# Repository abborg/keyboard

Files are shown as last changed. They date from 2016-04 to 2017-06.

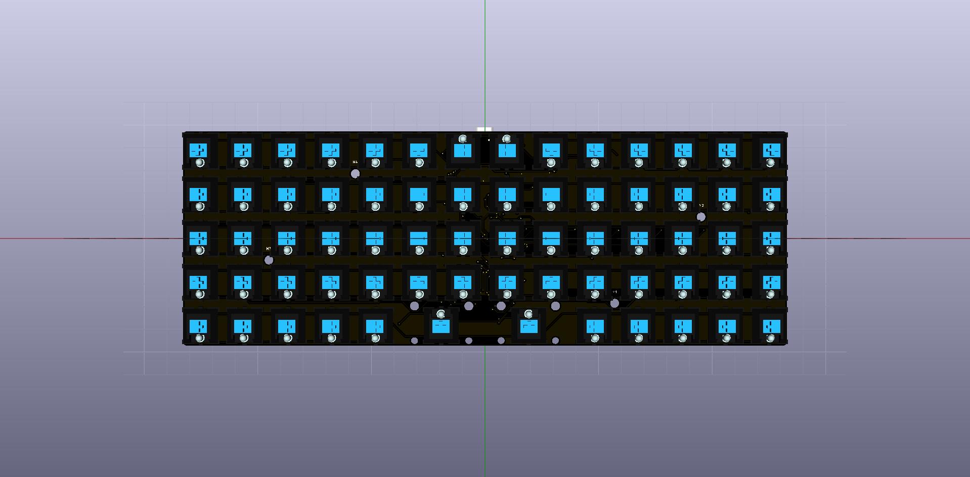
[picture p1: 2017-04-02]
KiCad/keyboard-front.jpg

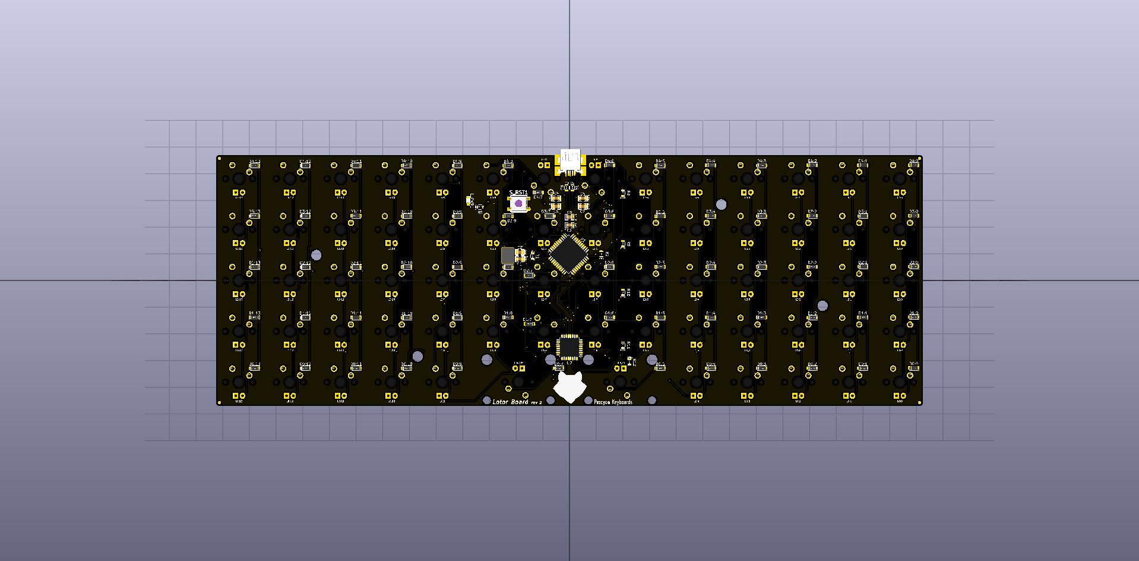
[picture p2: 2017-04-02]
KiCad/keyboard-back.jpg

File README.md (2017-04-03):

Keyboard
========

This repository is dedicated to information and the process of constructing my own custom mechanical keyboard. The hope is that this will be used to store my own notes and layout for future use or modification.

## Layout  

The layout is a unique design I have developed after studying other popular layouts. It has yet to be tested and will require a fair amount of getting used to compared to other layouts. It attempts to utilize the Workman layout and reduce the size of modifier keys. The layout was designed with intuition in mind. As such, much of the layout is symmetrical in an attempt to provide a regular structure to the placement of non-alphabet keys. The idea behind this is that one can make a good guess of where a symbol key is based upon the location of similar keys. Working with a keyboard with access to the microcontroller allows for the layout to be adjusted to suite the needs of the user. 

<sub>[View Layout](http://www.keyboard-layout-editor.com/#/gists/b67145701f86c79b1c43)</sub>  

Inspired by:
------------

Jack Humbert, of [Ortholinear Keyboards](www.ortholinearkeyboards.com)

Will Yager, with his [MicroMechBoard](http://yager.io/keyboard/keyboard.html)

The members of [r/olkb](http://www.reddit.com/r/olkb)

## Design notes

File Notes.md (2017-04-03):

## Metal:
Using 6061 aluminum 100mm x 273mm x 12mm bar for case  
Using 6061 aluminum 100mm x 273mm x 1.5mm sheet for plate  
MetalsDepot offers 0.5 inch x 4 inch 6061 Aluminum flat bar with custom length of 0' 10 3/4" for $15.93 + S/H  
MetalsDepot offers 0.063 inch thick 6061 Aluminum sheet with custom width of 4" and custom length of 0' 10 3/4" for $18.06 + S/H  
MetalsDepot total cost (w/ shipping) $63.39  

### Fabrication:
options to consider  
http://www.thetekmill.com/  
http://www.wagner-machine.com/  
http://www.shape-master.com/  

## Plate:
[Keyboard Layout Editor](http://www.keyboard-layout-editor.com/#/gists/b67145701f86c79b1c43)  
[Keyboard Plate CAD Drawer](http://builder.swillkb.com/)  

## Case:
275mm x 102.5mm x 13mm (l x w x h)
1mm radius outer top edge  
1mm radius inner top edge  
13mm x 1mm insets for rubber feet in corners (d x h)  
4.25mm x 8mm hole in center of back edge  
45° angle on bottom edge  

## Cover:
275mm x 102.5mm x 19mm (l x w x h)  
1mm radius outer bottom edge  
1mm radius inner bottom edge  
45° angle on top edge  

## PCB:
### Devices:
| Device Name | Num Required | Mouser Part # | Manufacturer Part # |
|--- |:---:|:---:|---:|
| ATMega32u4 | 1 | [556-ATMEGA32U4-AUR](http://www.mouser.com/ProductDetail/Microchip-Technology-Atmel/ATMEGA32U4-AUR/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) | ATMEGA32U4-AUR  |
| ATTiny88 | 1 | [556-ATTINY88-AU](http://www.mouser.com/ProductDetail/Microchip-Technology-Atmel/ATTINY88-AU/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) | ATTINY88-AU  |
|Resistor 22 Ohm | 2 | [71-CRCW0805J-22](http://www.mouser.com/ProductDetail/Vishay/CRCW080522R0JNTA/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)| CRCW080522R0JNTABC |
|Resistor 100 Ohm | 5 | [71-CRCW0805-100-E3](http://www.mouser.com/ProductDetail/Vishay/CRCW0805100RFKEA/?qs=sGAEpiMZZMu61qfTUdNhG2DpbjADlD3GxPcNG3UnvYk%3d)| CRCW0805100RFKEA |
|Resistor 10 kOhm | 2 | [71-CRCW080510K0FKEB](http://www.mouser.com/ProductDetail/Vishay/CRCW080510K0FKEB/?qs=sGAEpiMZZMu61qfTUdNhG2DpbjADlD3GcSqJrx4YWs0%3d)| CRCW080510K0FKEB |
|Resistor 140 Ohm | 1 | [71-CRCW0603-140-E3](http://www.mouser.com/ProductDetail/Vishay/CRCW0603140RFKEA/?qs=sGAEpiMZZMujMHSoaAZeGU0lxA%2fvZNWc)| CRCW0603140RFKEA |
|Crystal 16MHz | 1 |[581-CX3225CA16000PPQ](http://www.mouser.com/ProductDetail/AVX-Kyocera/CX3225CA16000P0HPQCC/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) | CX3225CA16000P0HPQCC |
|Capacitor 22pF |2 | [77-VJ0805A220GXXCBC](http://www.mouser.com/ProductDetail/Vishay/VJ0805A220GXXCW1BC/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)| VJ0805A220GXXCW1BC |
| Capacitor 1uF | 2 | [77-VJ0805Y105JXQTBC](http://www.mouser.com/ProductDetail/Vishay/VJ0805Y105JXQTW1BC/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)| VJ0805Y105JXQTW1BC |
| Capacitor 0.1uF | 6 | [77-VJ0805Y104JXXAC](http://www.mouser.com/ProductDetail/Vishay/VJ0805Y104JXXAC/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)| VJ0805Y104JXXAC |
| Cherry Mx Clear | 68 | [540-MX1A-C1NW](http://www.mouser.com/ProductDetail/CHERRY/MX1A-C1NW/?qs=%2fha2pyFaduhq8Eet0S7vJZRQrJ5ARolZRjRGrDPgpGI%3d) | MX1A-C1NW |
| Diode | 68 | [78-1N4148W-E3-18](http://www.mouser.com/ProductDetail/Vishay-Semiconductors/1N4148W-E3-18/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) | 1N4148W-E3-18 |
| Keyswitch LED | 68 |  [828-OVLAW4CB7](http://www.mouser.com/ProductDetail/TT-Electronics/OVLAW4CB7/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) | OVLAW4CB7 |
| Power LED | 1 |  [630-HSMG-C170](http://www.mouser.com/ProductDetail/Broadcom-Limited/HSMG-C170/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) | HSMG-C170 |
| Switch | 1 | [642-DTSMW67T](http://www.mouser.com/ProductDetail/Apem/ADTSMW67TV/?qs=sGAEpiMZZMsgGjVA3toVBOI7nILP73PyWCtsFyAcyoI%3d) | ADTSMW67TV |
| Mini USB-B Connector | 1 | [538-67503-1020](http://www.mouser.com/ProductDetail/Molex/67503-1020/?qs=sGAEpiMZZMtDa8bhoiaN7Dp%2fkqK5DKnm) | 67503-1020 |

PCB will support grid or MIT-esque layouts and standard placement of capslock LED. Also supports FN key light and bottom right corner capslock.

### Fabrication:
[4pcb.com: $33 each boards](www.4pcb.com)

## Miscellaneous
### USB cable:
[/u/90N1NE's Cord Form](https://docs.google.com/forms/d/1O8-y3vcuR8QClX1kB-gxhwCaVJ4b8tqBf4mBuyMltoc)  
[Pexon's Store](http://pexonpcs.co.uk/)  
[/u/jchan94's Cord Form](https://docs.google.com/forms/d/1i3O6ZZ9YgS6CADAT-xIyotbfbr2Xl6MgCU8oeTNEtNQ/viewform)

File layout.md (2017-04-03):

### [Borgman Layout](http://www.keyboard-layout-editor.com/#/gists/b67145701f86c79b1c43)
```
[{a:7},"",{a:4},"Esc","<\n0","_\n1","@\n2","#\n3","$\n4","%\n5","^\n6","`\n7","*\n8",">\n9","~\n\\",{a:7},""],
["",{a:4},"|\n[\n\n\nF1","Q\n\n\n\nF2","D\n\n\n\nF3","R\n\n\n\nF4","W\n\n\n\nF5","B\n\n\n\nF6","J\n\n\n\nF7","F\n\n\n\nF8","U\n\n\n\nF9","P\n\n\n\nF10",{p:"R1"},"Z\n\n\n\nF11","&\n]\n\n\nF12",{a:7},""],
[{a:4},"Tab","{\n'","A","S","H",{n:true},"T","G","Y",{n:true},"N","E","O","I","}\n\"","Enter"],
["Shift","(\n:","=\n-","!\n,","X","M","C","V","K","L","?\n.","+\n/",")\n;","Shift"],
["Ctrl","Alt","Super","Fn","Del",{w:2},"Bksp",{w:2},"Space","&larr;","&darr;","&uarr;","&rarr;","Caps Lock"]
```

### [Qwerty Layout](http://www.keyboard-layout-editor.com/#/gists/a3920c732301a2b1e937)
```
[{a:7},"",{a:4},"Esc","(\n0","!\n1","@\n2","#\n3","$\n4","%\n5","^\n6","&\n7","*\n8",")\n9","|\n\\",{a:7},""],
["",{a:4},"{\n[\n\n\nF1","Q\n\n\n\nF2","W\n\n\n\nF3","E\n\n\n\nF4","R\n\n\n\nF5","T\n\n\n\nF6","Y\n\n\n\nF7","U\n\n\n\nF8","I\n\n\n\nF9","O\n\n\n\nF10","P\n\n\n\nF11","}\n]\n\n\nF12",{a:7},""],
[{a:4},"Tab","~\n`","A","S","D",{n:true},"F","G","H",{n:true},"J","K","L",":\n;","\"\n'","Enter"],
["Shift","_\n-","Z","X","C","V","B","N","M","<\n,",">\n.","?\n/","+\n=","Shift"],
["Ctrl","Alt","Super","Fn","Del",{w:2},"Bksp",{a:7,w:2},"",{a:4},"&larr;","&darr;","&uarr;","&rarr;","Caps Lock"]
```

### [Borgman Grid](http://www.keyboard-layout-editor.com/#/gists/bce03da974b8195c0e16)
```
[{y:0.5,a:7},"",{a:4},"Esc","(\n0","!\n1","@\n2","#\n3","$\n4","%\n5","^\n6","&\n7","*\n8",")\n9","|\n\\",{a:7},""],
["",{a:4},"{\n[\n\n\nF1","Q\n\n\n\nF2","D\n\n\n\nF3","R\n\n\n\nF4","W\n\n\n\nF5","B\n\n\n\nF6","J\n\n\n\nF7","F\n\n\n\nF8","U\n\n\n\nF9","P\n\n\n\nF10",":\n;\n\n\nF11","}\n]\n\n\nF12",{a:7},""],
[{a:4},"Tab","~\n`","A","S","H",{n:true},"T","G","Y",{n:true},"N","E","O","I","\"\n'","Enter"],
["Shift","_\n-","Z","X","M","C","V","K","L","<\n,",">\n.","?\n/","+\n=","Shift"],
["Ctrl","Alt","Super","Fn","Del","Bksp",{a:7},"","",{a:4},"Space","&larr;","&darr;","&uarr;","&rarr;","Caps Lock"]
```

### [Qwerty Grid](http://www.keyboard-layout-editor.com/#/gists/328b5f2f2a083147eaa4ffbb5ecdb029)
```
[{a:7},"",{a:4},"Esc","(\n0","!\n1","@\n2","#\n3","$\n4","%\n5","^\n6","&\n7","*\n8",")\n9","|\n\\",{a:7},""],
["",{a:4},"{\n[\n\n\nF1","Q\n\n\n\nF2","W\n\n\n\nF3","E\n\n\n\nF4","R\n\n\n\nF5","T\n\n\n\nF6","Y\n\n\n\nF7","U\n\n\n\nF8","I\n\n\n\nF9","O\n\n\n\nF10","P\n\n\n\nF11","}\n]\n\n\nF12",{a:7},""],
[{a:4},"Tab","~\n`","A","S","D",{n:true},"F","G","H",{n:true},"J","K","L",":\n;","\"\n'","Enter"],
["Shift","_\n-","Z","X","C","V","B","N","M","<\n,",">\n.","?\n/","+\n=","Shift"],
["Ctrl","Alt","Super","Fn","Del","Bksp",{a:7},"","",{a:4},"Space","&larr;","&darr;","&uarr;","&rarr;","Caps Lock"]
```

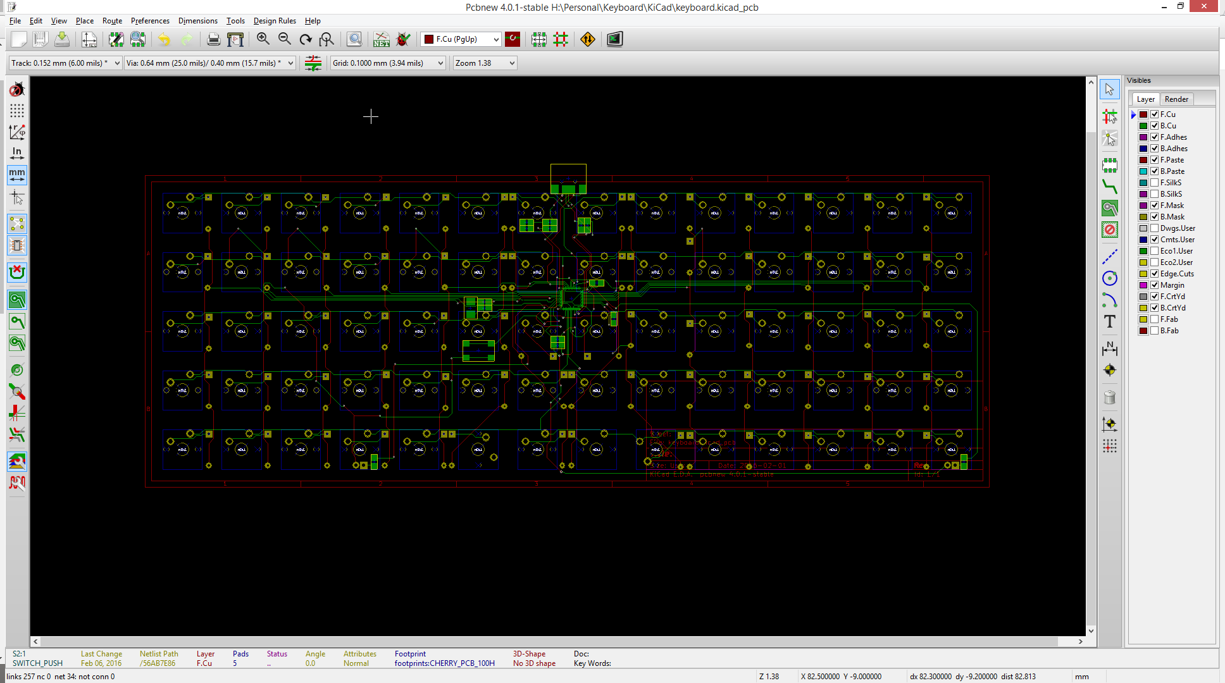
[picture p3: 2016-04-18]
Images/pcb-design-4-17-16.PNG

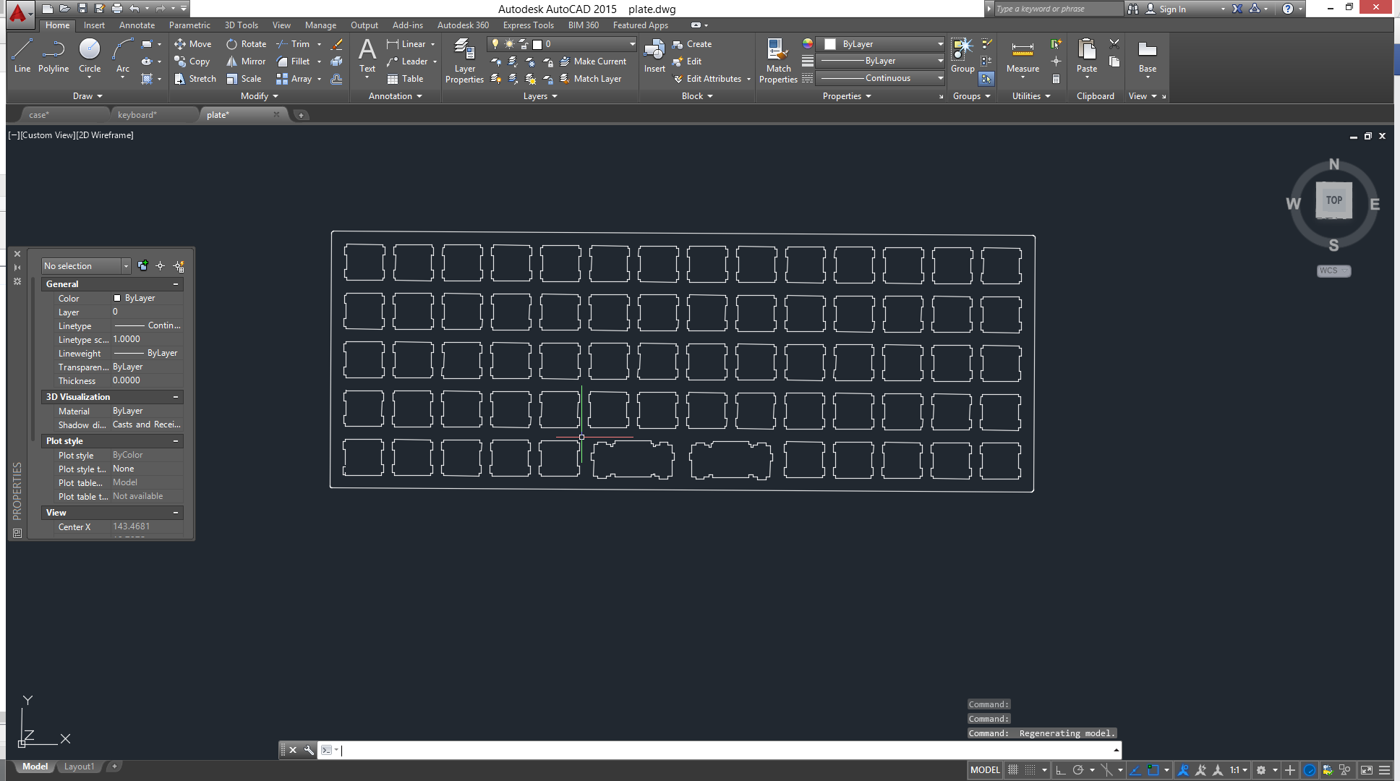
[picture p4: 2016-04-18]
Images/top-plate-4-14-16.PNG

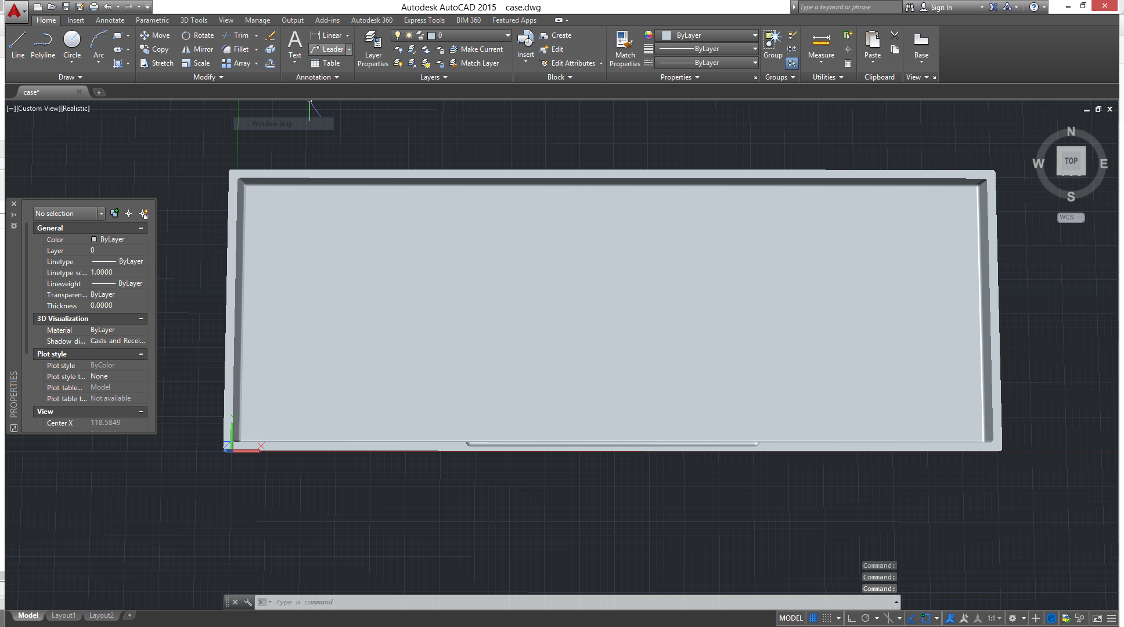
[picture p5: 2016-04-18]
Images/case-bottom-4-14-16.PNG

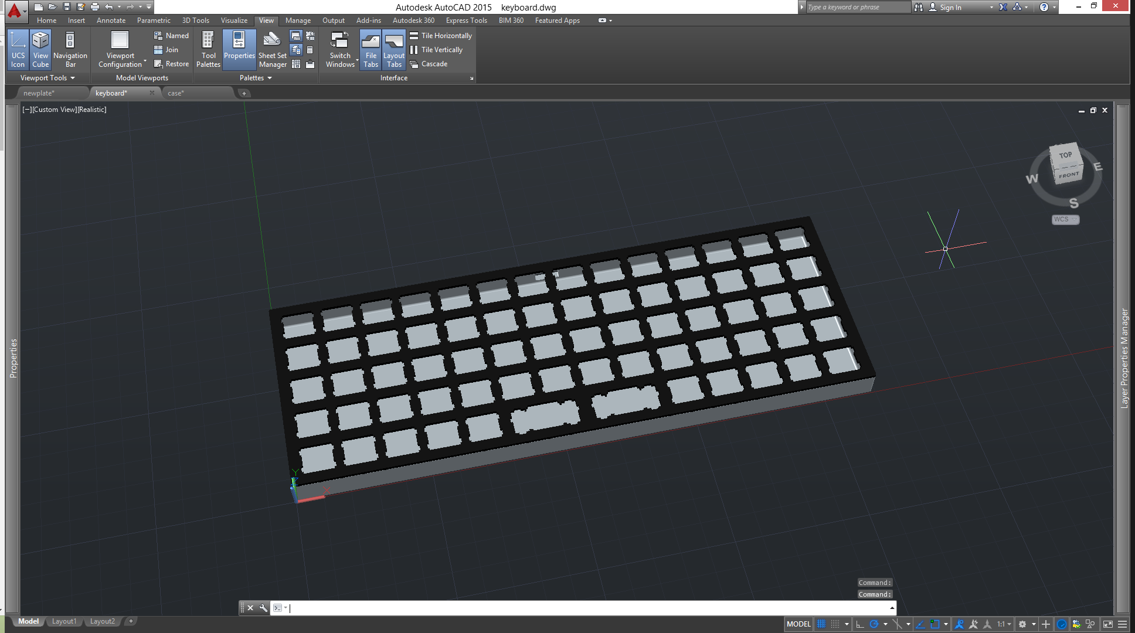
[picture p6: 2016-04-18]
Images/keyboard-4-16-16.PNG

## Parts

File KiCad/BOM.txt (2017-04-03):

MCU Section (0805 components)
Ref       Value         Quantity    Footprint       Part                            Description    
----------------------------------------------------------------------------------------------------------------------
C1,C2     22pF          2           0805            VJ0805A220GXXCW1BC      
C3,C4     1uF           2           0805            VJ0805Y105JXQTW1BC      
C5..C10   0.1uF         6           0805            VJ0805Y104JXXAC 
R1,R2     10 kOhm       2           0805            CRCW080510K0FKEB
R3,R4     22 Ohm        2           0805            CRCW080522R0JNTABC
R5        140 Ohm       1           0805            CRCW0603140RFKEA
R6..R10   100 Ohm       5           0805            CRCW0805100RFKEA

MCU Section (Common)
Ref       Value         Quantity    Footprint       Part                            Description    
----------------------------------------------------------------------------------------------------------------------
X1        16MHz         1           3.2 x 3.2       CX3225CA16000P0HPQCC                 16MHz, 18pf load capacitance, 3.2mm x 2.5mm, 10ppm tolerance & stability
S_RST1    Switch        1           6.3 x 6.2       ADTSMW67TV                      Tactile Switch 6.30 x 6.20 mm
J1        USB MINI-B    1                           67503-1020                      Molex USB Mini-B Recept On-The-Go Rt.Angle                             
U1        ATMEGA32U4    1           TQFP44          ATMEGA32U4-AU                   
U2        ATTINY88      1           TQFP32          ATTINY88-AU

Keyboard Section
Ref       Value         Quantity    Footprint       Part                            Description    
----------------------------------------------------------------------------------------------------------------------
Switches  MX1A          68          CHERRY MX       
D0:0-4:13 1N4148        68          SOD-123         1N4148W-E3-08                   1N4148
L0:0-4:13 LED           68          3mm             OVLAW4CB7                       White 3.2V 20mA LED
L_PWR1                  1           0805            HSMG-C170                       Green 2.2V 20mA LED

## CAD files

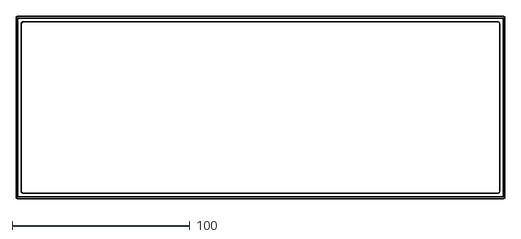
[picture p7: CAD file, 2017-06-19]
AutoCAD/2d/coverbottom.dxf
275.0 x 102.5

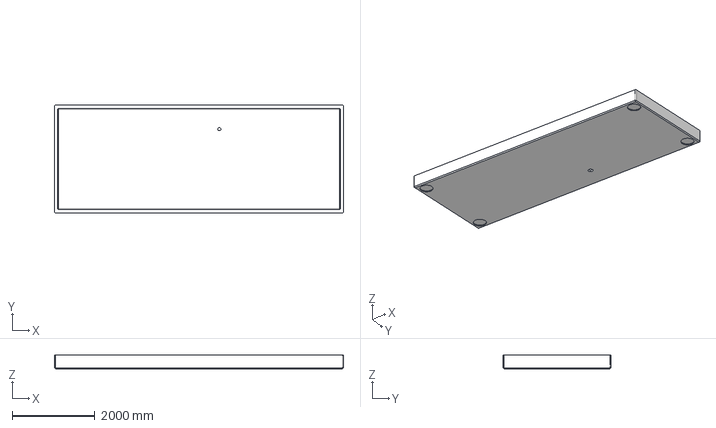
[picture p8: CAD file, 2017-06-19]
AutoCAD/case.igs
6985.0 x 2603.5 x 330.2 mm

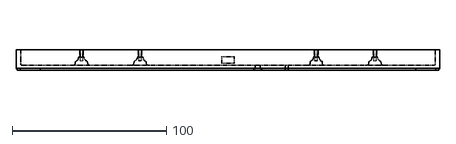
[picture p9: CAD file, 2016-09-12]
AutoCAD/Plots/casefrontview.dxf
275.0 x 13.0

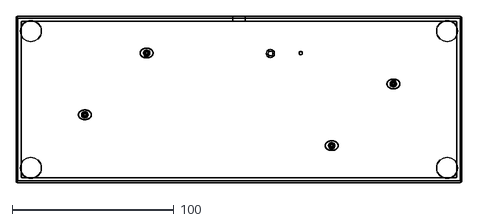
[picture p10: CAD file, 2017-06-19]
AutoCAD/2d/casetop.dxf
275.0 x 102.5

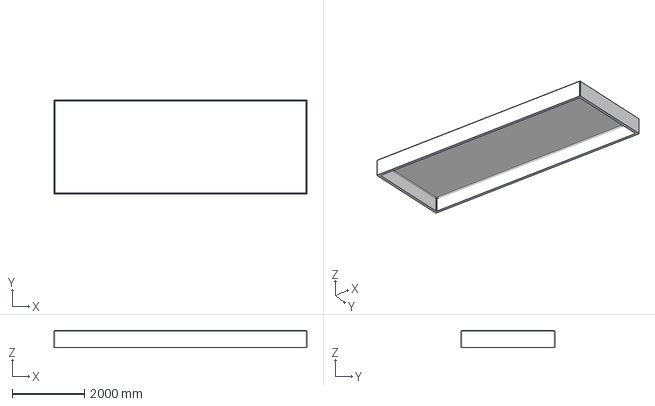
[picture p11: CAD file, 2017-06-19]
AutoCAD/cover.igs
6985.0 x 2603.5 x 482.6 mm

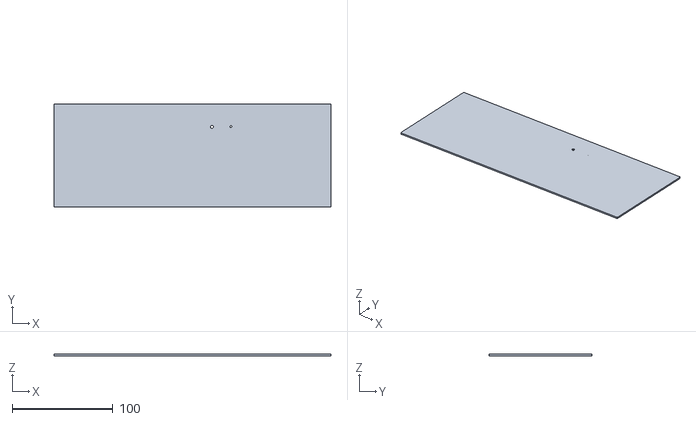
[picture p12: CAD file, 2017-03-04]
AutoCAD/bottom.stl
275.0 x 102.5 x 1.50

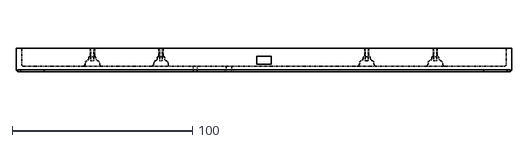
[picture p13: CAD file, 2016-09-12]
AutoCAD/Plots/casebackview.dxf
275.0 x 13.0

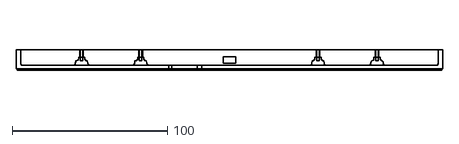
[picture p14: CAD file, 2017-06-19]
AutoCAD/2d/caseback.dxf
275.0 x 13.0

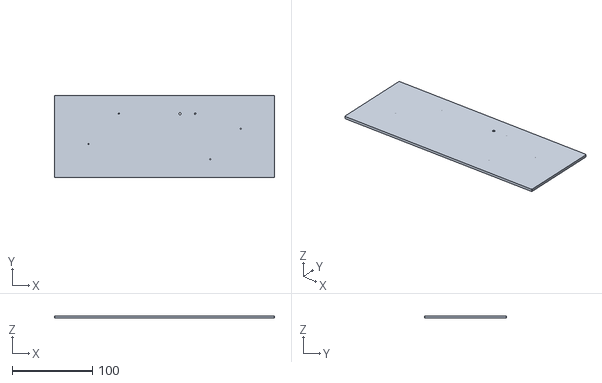
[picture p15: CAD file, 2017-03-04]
AutoCAD/bottom-middle.stl
275.0 x 102.5 x 3.00

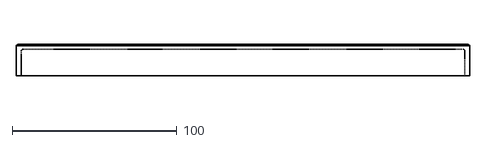
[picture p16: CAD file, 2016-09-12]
AutoCAD/Plots/coverbackview.dxf
275.0 x 19.0

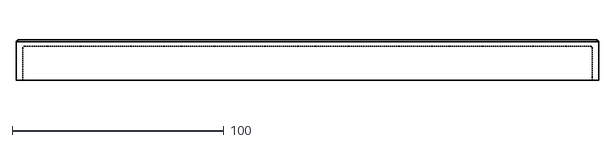
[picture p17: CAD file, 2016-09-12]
AutoCAD/Plots/coverfrontview.dxf
275.0 x 19.0

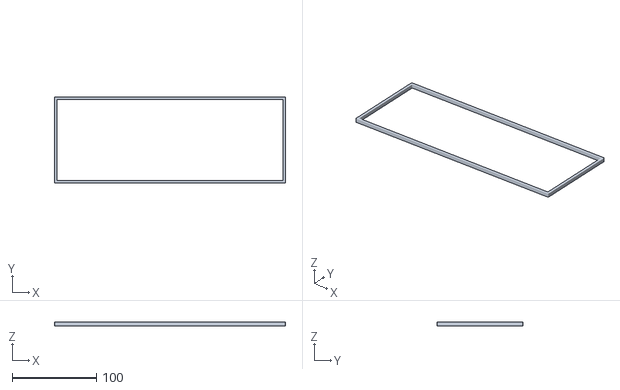
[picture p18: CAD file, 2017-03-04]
AutoCAD/top.stl
275.0 x 102.5 x 4.50

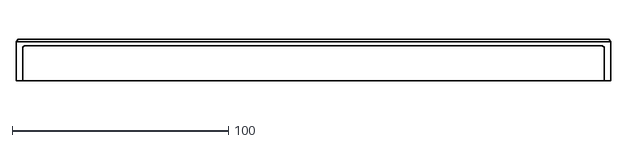
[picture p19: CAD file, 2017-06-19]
AutoCAD/2d/coverback.dxf
275.0 x 19.0

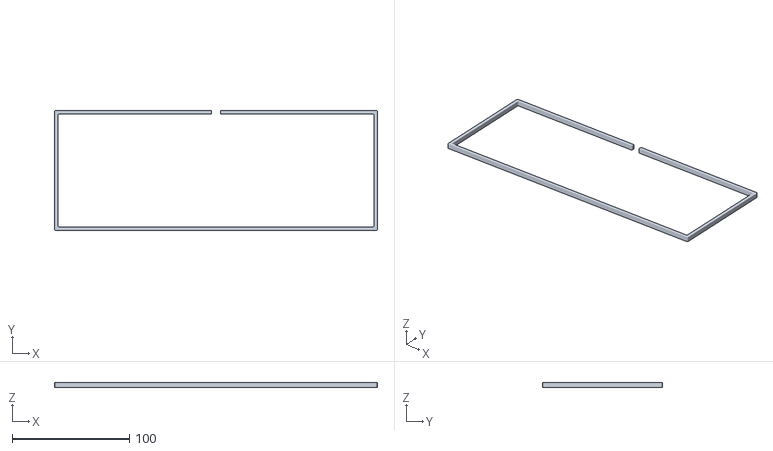
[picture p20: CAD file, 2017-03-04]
AutoCAD/top-middle.stl
275.0 x 102.5 x 4.50

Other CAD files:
AutoCAD/Plots/caseleftview.dxf
AutoCAD/2d/caseright.dxf
AutoCAD/2d/coverright.dxf
AutoCAD/Plots/caserightview.dxf
AutoCAD/Plots/casebottomview.dxf
AutoCAD/Plots/casetopview.dxf
AutoCAD/Plots/coverbottomview.dxf
AutoCAD/Plots/coverleftview.dxf
AutoCAD/Plots/coverrightview.dxf
AutoCAD/Plots/covertopview.dxf
AutoCAD/bottom-middle.dwg
AutoCAD/bottom.dwg
AutoCAD/case.dwg
AutoCAD/case.stl
AutoCAD/cover.dwg
AutoCAD/cover.dxf
AutoCAD/cover.stl
AutoCAD/keyboard.dwg
AutoCAD/plate-MIT.dxf
AutoCAD/plate-grid.dxf
AutoCAD/slices.dwg
AutoCAD/slices.dxf
AutoCAD/slices.stl
AutoCAD/thick-plate-grid.dwg
AutoCAD/thick-plate-grid.stl
AutoCAD/thick_plate-MIT.dwg
AutoCAD/thick_plate-MIT.stl
AutoCAD/top-middle.dwg
AutoCAD/top.dwg

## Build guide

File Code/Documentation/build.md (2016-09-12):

Build Firmware and Program Controller
=====================================

Download and Install
--------------------
### 1. Install Tools

1. **Toolchain** On Windows install [Atmel AVR Toolchain][atmelgcc] for AVR GCC compiler and [Cygwin][cygwin](or [MinGW][mingw]) for shell terminal. On Mac you can use [CrossPack][crosspack] or your favorite package manager. On Linux you can install AVR GCC with your favorite package manager.

2. **Programmer** Install [dfu-programmer][dfu-prog]. GUI tool [Atmel FLIP][flip] also can be used on Windows.

3. **Driver** On Windows when you start DFU bootloader on the chip first time you will see **Found New Hardware Wizard** to install driver. If you install device driver properly you will find chip name like **ATmega32U4** under **LibUSB-Win32 Devices** tree on **Device Manager**. If not you shall need to update its driver on **Device Manager**. You will find the driver in `FLIP` install directory like: `C:\Program Files (x86)\Atmel\Flip 3.4.5\usb\`. In case of `dfu-programmer` install driver distributed with it.

If you use PJRC Teensy you don't need step 2 and 3 above, just get [Teensy loader][teensy-loader].

### 2. Download source
You can find firmware source at github:

- <https://github.com/tmk/tmk_keyboard>

If you are familiar with [`git`][git] tools you are recommended to use it but you can also download zip archive from:

- <https://github.com/tmk/tmk_keyboard/archive/master.zip>

Build firmware
--------------
### 1. Open terminal
Open terminal window to get access to commands. Use Cygwin(or MingGW) shell terminal in Windows or `Terminal.app` on Mac OSX.

### 2. Change directory
Move to project directory in the firmware source.

    cd tmk_keyboard/{'keyboard' or 'converter'}/<project>

### 3. Make
Build firmware using GNU `make` command. You'll see `<project>_<variant>.hex` file in that directory unless something unexpected occurs in build process.

    make -f Makefile.<variant> clean
    make -f Makefile.<variant>

Program Controller
------------------
Now you have **hex** file to program on current directory. This **hex** is only needed to program your controller, other files are used for development and you may leave and forget them.

### 1. Start bootloader
How to program controller depends on controller chip and its board design. To program AVR USB chips you'll need to start it up in bootloader mode. Most of boards with the chip have a push button to let bootloader come up. Consult with your controller board manual.

### 2. Program with DFU bootloader
Stock AVR USB chips have DFU bootloader by factory default. `FLIP` is a DFU programmer on Windows offered by Atmel. `FLIP` has two version of tool, GUI app and command line program. If you want GUI see tutorial below. Open source alternative `dfu-programmer` also supports AVR chips, it is command line tool and runs on Linux, Mac OSX and even Windows.

To program with command of `FLIP` run this. Note that you need to set PATH variable properly.

    $ make -f Makefile.<variant> flip

With `dfu-programmer` run this.

    $ make -f Makefile.<variant> dfu

Or you can execute the command directly as the following.

    $ dfu-programmer <controller> erase --force
    $ dfu-programmer <controller> flash <your_firmware.hex>
    $ dfu-programmer <controller> reset

`<controller>` part will be `atmega32u4` or `atmega32u2` in most cases. See manual of the command for the detail. On Linux and Mac OSX you will need proper permission to program a controller and you can use `sudo` command for this purpose probably. On Linux you also can configure `udev` rules to set permission.

#### FLIP GUI tutorial
1. On menu bar click **Device** -> **Select**, then choose your chip name. (In most cases **ATmega32U2** or **ATmega32U4**)
2. On menu bar click **Settings** -> **Communication** -> **USB**, then click **Open** button on **USB Port Connection** dialog. At this point you'll have to plug into USB and start bootloader.

3. On menu bar click **File** -> **Load HEX File**, then select your firmware hex file on File Selector dialog.
4. On **Operations Flow** panel click **Run** button to load the firmware binary to the chip. Note that you should keep **Erase**, **Blank Check**, **Program** and **Verify** check boxes selected.
5. Re-plug USB cord or click **Start Application** button to restart your controller.
Done.

See also these instructions if needed.

- <http://code.google.com/p/micropendous/wiki/LoadingFirmwareWithFLIP>
- <http://www.atmel.com/Images/doc7769.pdf>

##### Troubleshoot
* **FLIP: AtLibUsbDfu.dll not found**
Remove current driver and re-install one FLIP provides from DeviceManager of WIndows. See <http://imgur.com/a/bnwzy>

### 3. Program with Other programmer
If you are using PJRC Teensy consult with instruction of [Teensy Loader][teensy-loader]. Or run this target with `make` after you install command line version of it.

    $ make -f Makefile.<variant> teensy

You may want to use other programmer like [`avrdude`][avrdude]. In that case you can still use make target `program` for build with configuring `PROGRAM_CMD` in Makefile. See below.

    $ make -f Makefile.<variant> program

[atmelgcc]:     http://www.atmel.com/tools/ATMELAVRTOOLCHAINFORWINDOWS.aspx
[cygwin]:       https://www.cygwin.com/
[mingw]:        http://www.mingw.org/
[crosspack]:    http://www.obdev.at/products/crosspack/index.html
[flip]:         http://www.atmel.com/tools/FLIP.aspx
[dfu-prog]:     http://dfu-programmer.sourceforge.net/
[teensy-loader]:http://www.pjrc.com/teensy/loader.html
[avrdude]:      http://savannah.nongnu.org/projects/avrdude/
[git]:          https://git-scm.com/

Makefile Options
----------------
### 1. MCU and Frequency.

    MCU = atmega32u4       # Teensy 2.0
    #MCU = at90usb1286      # Teensy++ 2.0
    F_CPU = 16000000

Set your MCU and its clock in Hz.

    # Boot Section Size in *bytes*
    #   Teensy halfKay   512
    #   Teensy++ halfKay 2048
    #   Atmel DFU loader 4096
    #   LUFA bootloader  4096
    OPT_DEFS += -DBOOTLOADER_SIZE=4096

If you are using PJRC Teensy use `512` for `BOOTLOADER_SIZE`, otherwise use `4096` unless you are sure.

### 2. Features
Optional. Note that ***comment out*** with `#` to disable them.

    BOOTMAGIC_ENABLE = yes      # Virtual DIP switch configuration(+1000)
    MOUSEKEY_ENABLE = yes       # Mouse keys(+4700)
    EXTRAKEY_ENABLE = yes       # Audio control and System control(+450)
    CONSOLE_ENABLE = yes        # Console for debug(+400)
    COMMAND_ENABLE = yes        # Commands for debug and configuration
    SLEEP_LED_ENABLE = yes      # Breathing sleep LED during USB suspend
    #NKRO_ENABLE = yes          # USB Nkey Rollover - not yet supported in LUFA
    #BACKLIGHT_ENABLE = yes     # Enable keyboard backlight functionality

### 3. Programmer
Optional. Set proper command for your controller, bootloader and programmer. This command can be used with `make program`.

    # avrdude with AVRISPmkII
    PROGRAM_CMD = avrdude -p $(MCU) -c avrispmkII -P USB -U flash:w:$(TARGET).hex

    # avrdude with USBaspLoader
    PROGRAM_CMD = avrdude -p $(MCU) -c usbasp -U flash:w:$(TARGET).hex

    # avrdude with arduino
    PROGRAM_CMD = avrdude -p $(MCU) -c arduino -P COM1 -b 57600 -U flash:w:$(TARGET).hex

Config.h Options
----------------
### 1. Magic command key combination

    #define IS_COMMAND() (keyboard_report->mods == (MOD_BIT(KB_LSHIFT) | MOD_BIT(KB_RSHIFT)))

### 2. Mechanical Locking Support for CapsLock

    /* Mechanical locking CapsLock support. Use KC_LCAP instead of KC_CAPS in keymap */
    #define CAPSLOCK_LOCKING_ENABLE
    /* Locking CapsLock re-synchronize hack */
    #define CAPSLOCK_LOCKING_RESYNC_ENABLE

### 3. Disable Debug and Print

    /* disable debug print */
    #define NO_DEBUG

    /* disable print */
    #define NO_PRINT

### 4. Disable Action Features

    #define NO_ACTION_LAYER
    #define NO_ACTION_TAPPING
    #define NO_ACTION_ONESHOT
    #define NO_ACTION_MACRO
    #define NO_ACTION_FUNCTION

***TBD***

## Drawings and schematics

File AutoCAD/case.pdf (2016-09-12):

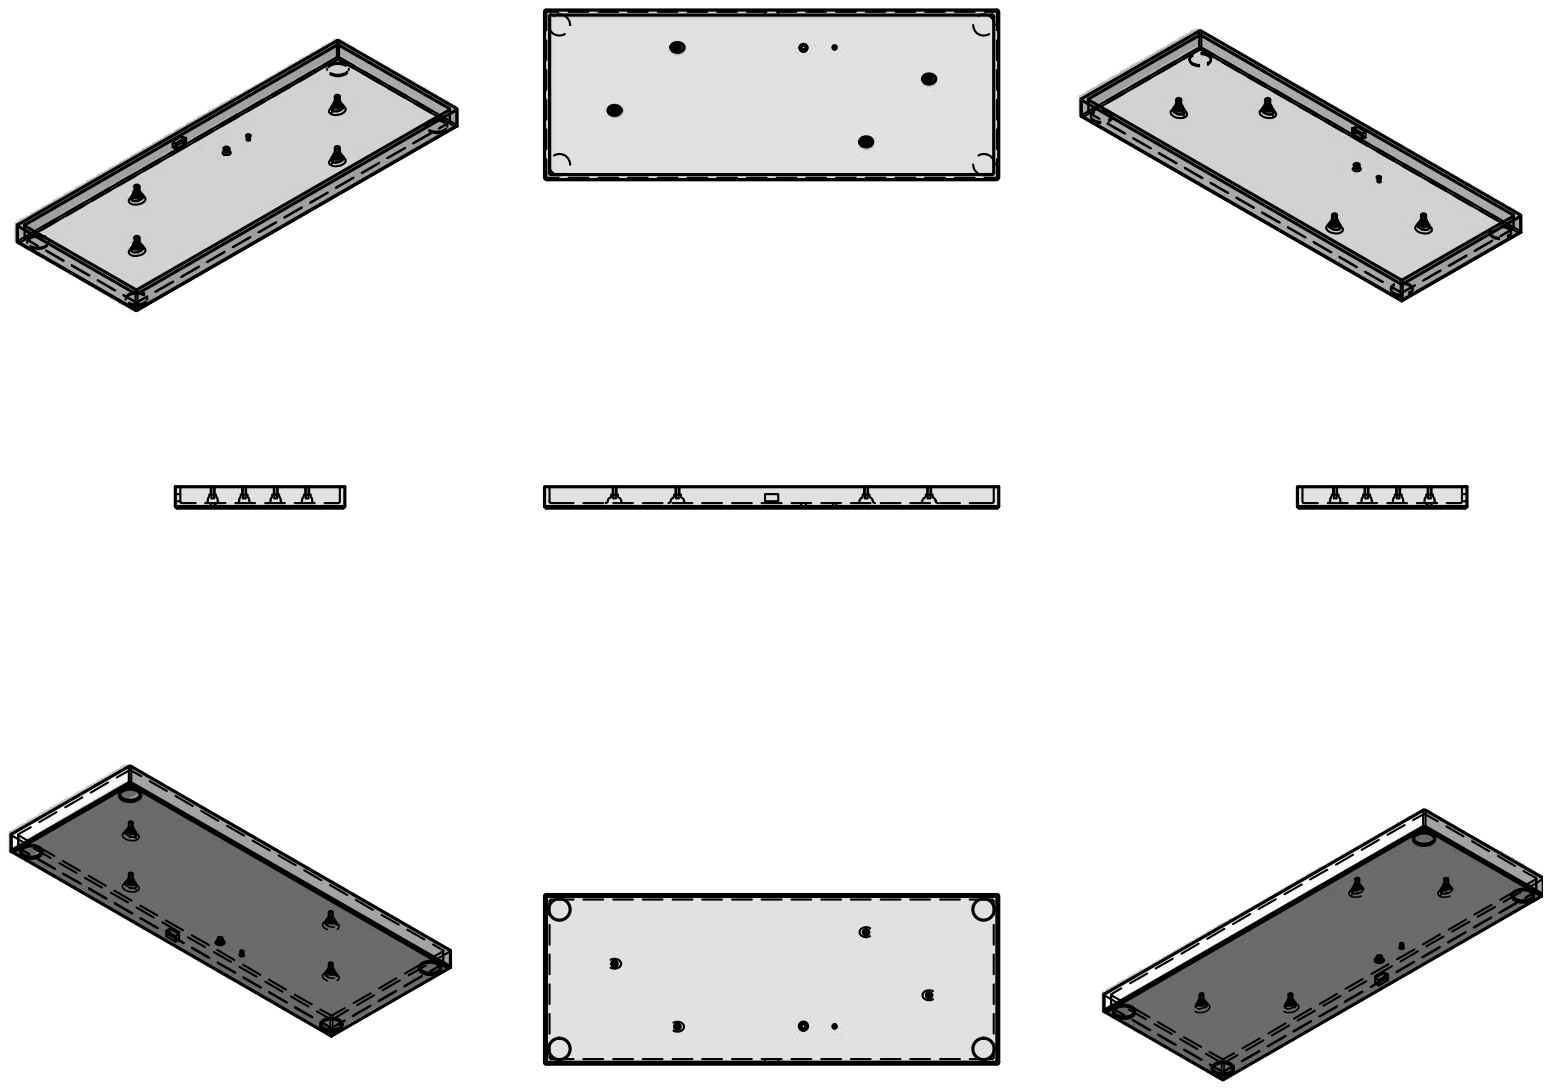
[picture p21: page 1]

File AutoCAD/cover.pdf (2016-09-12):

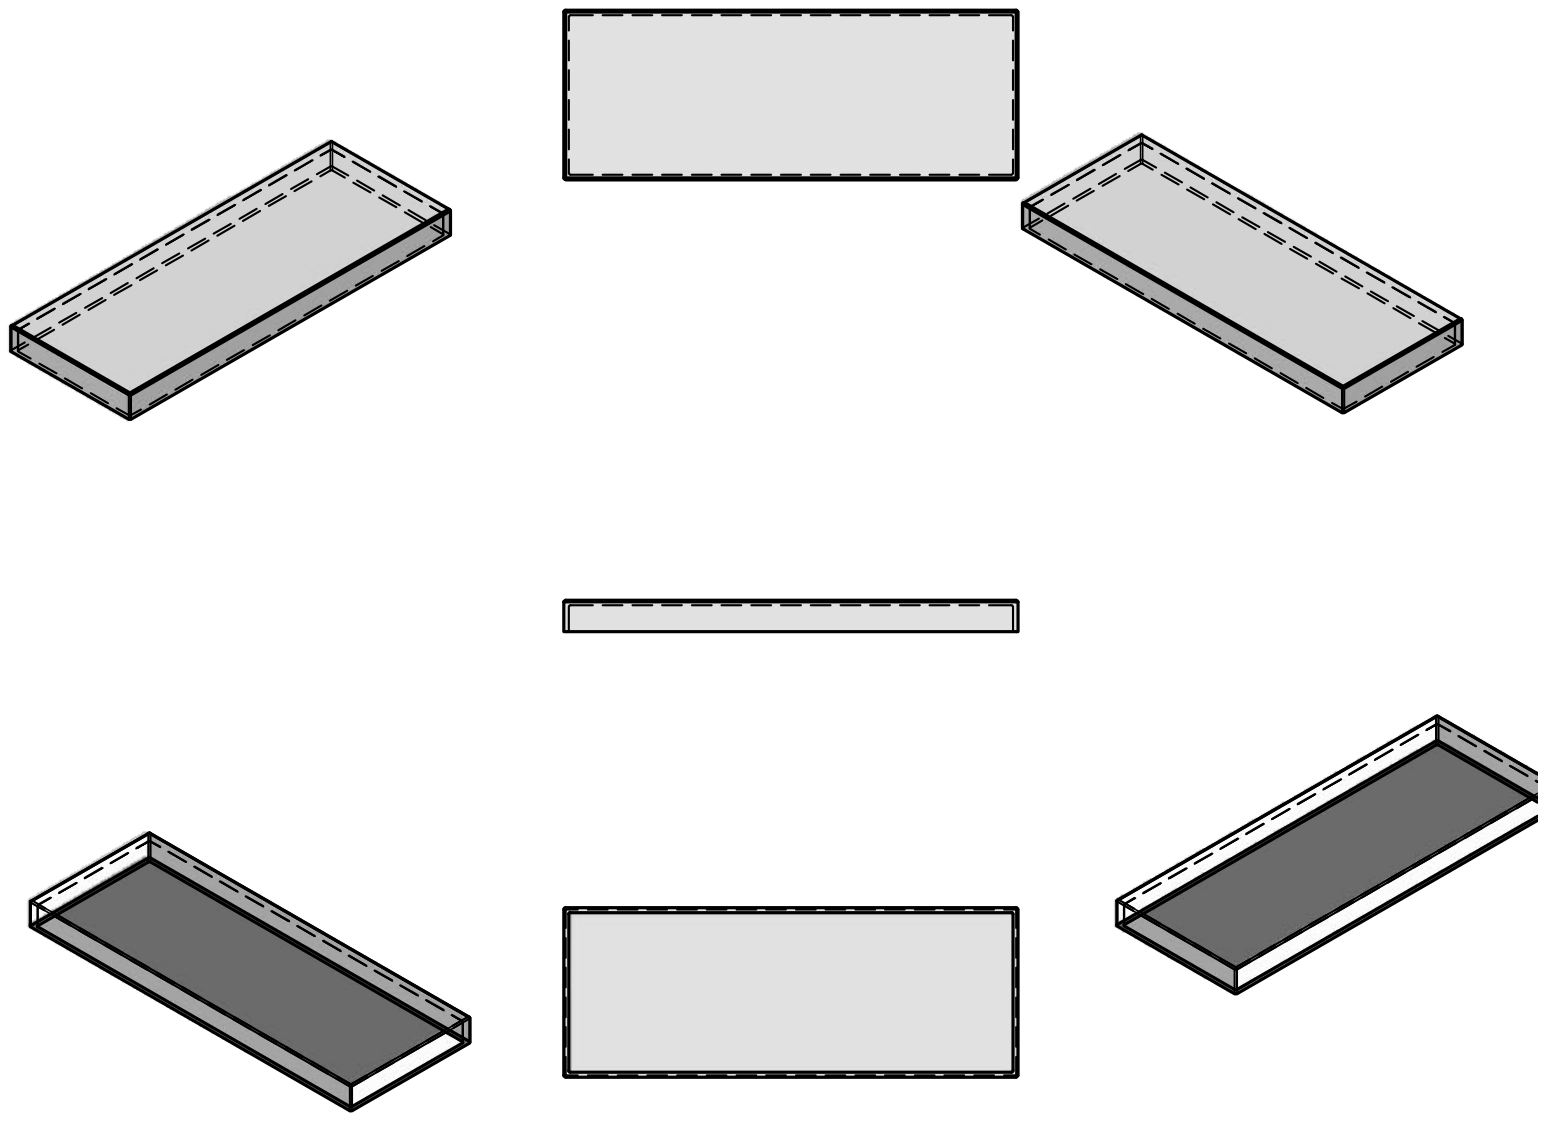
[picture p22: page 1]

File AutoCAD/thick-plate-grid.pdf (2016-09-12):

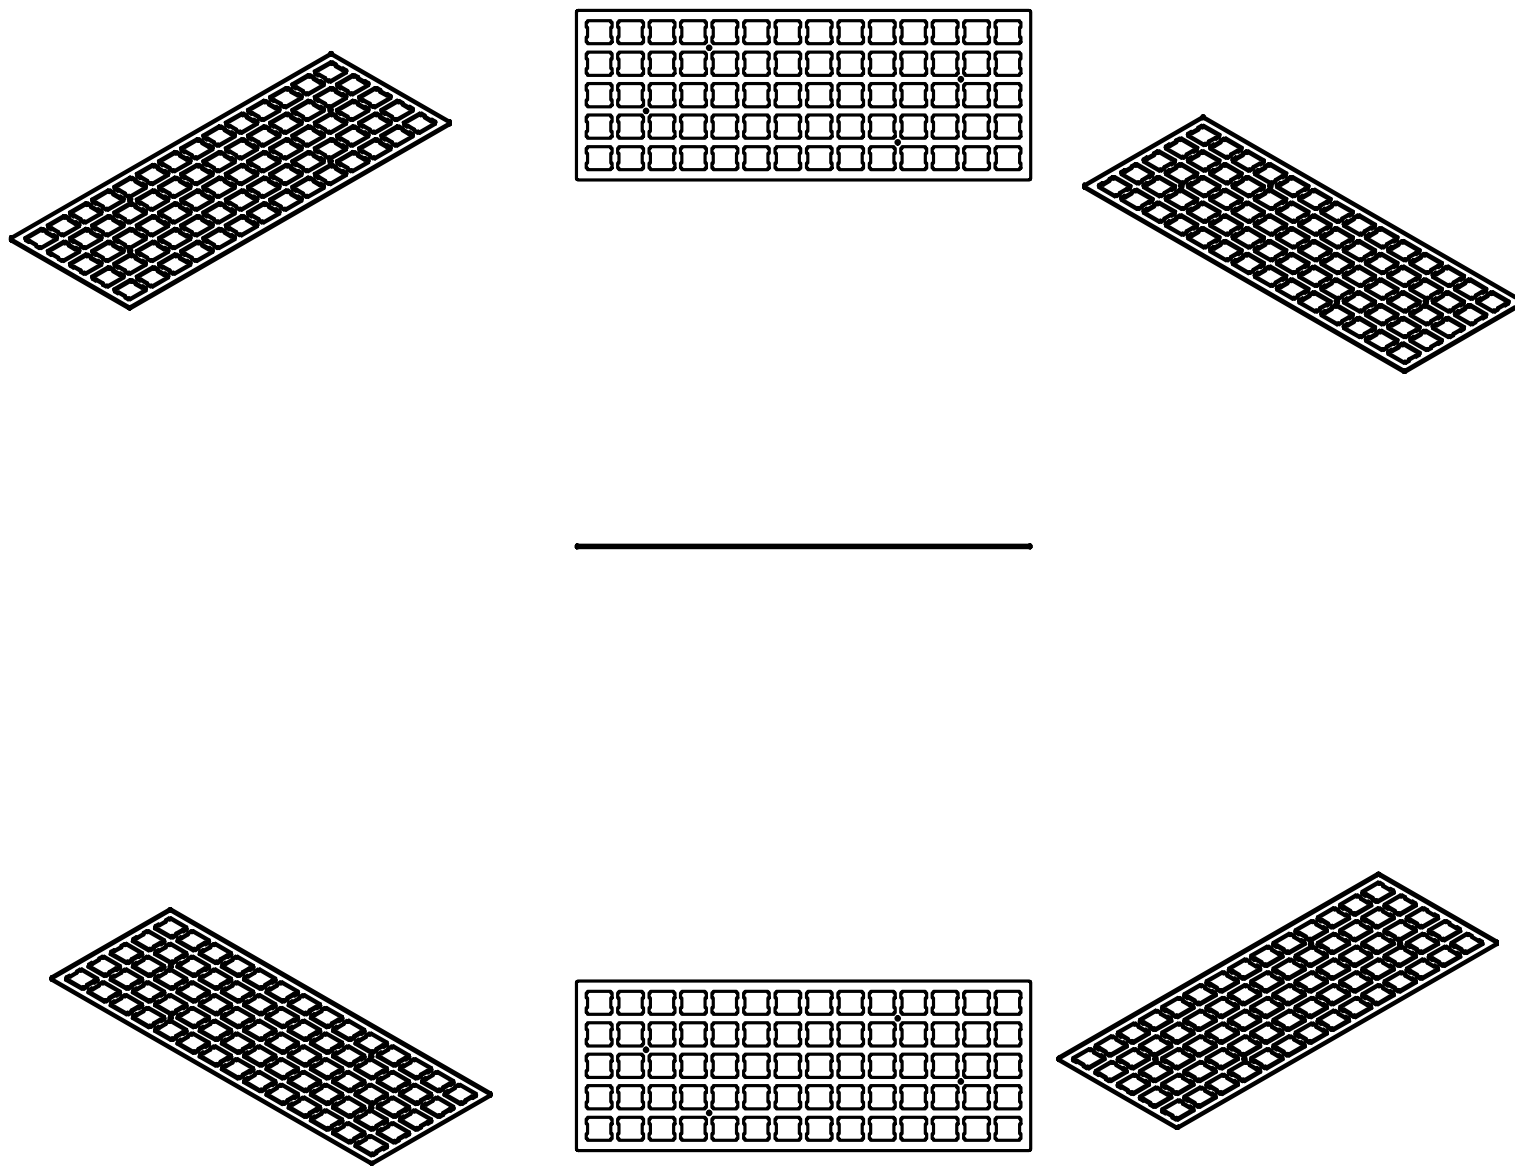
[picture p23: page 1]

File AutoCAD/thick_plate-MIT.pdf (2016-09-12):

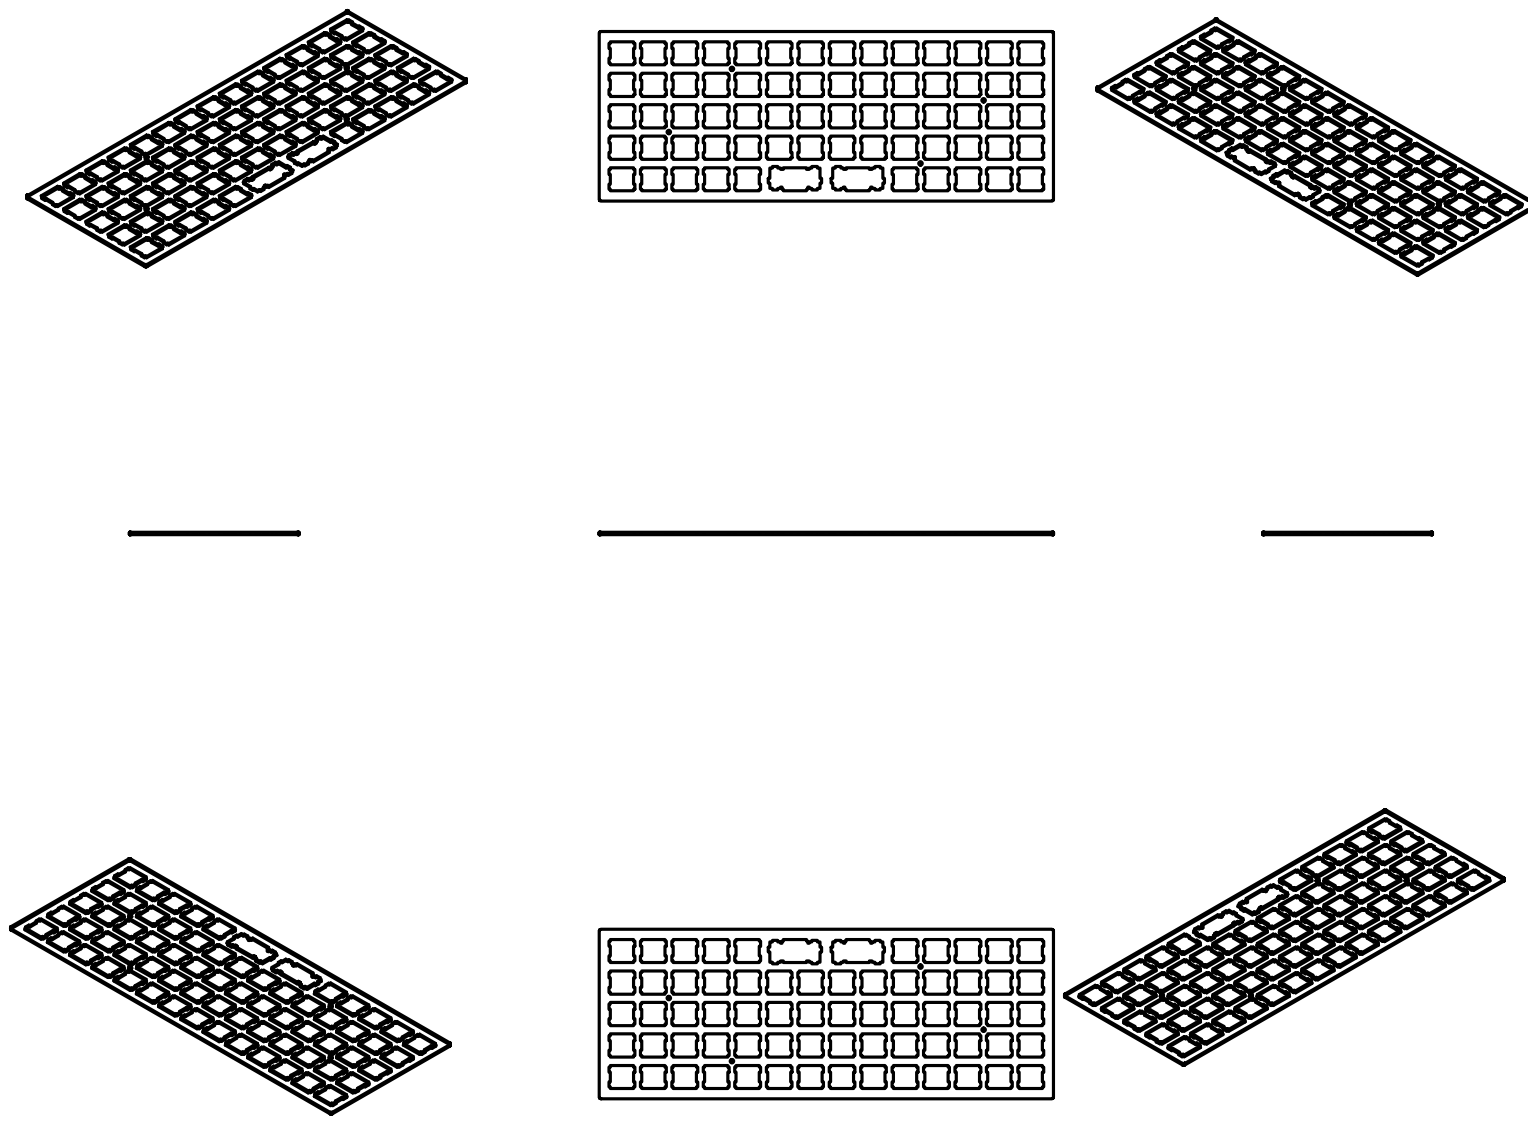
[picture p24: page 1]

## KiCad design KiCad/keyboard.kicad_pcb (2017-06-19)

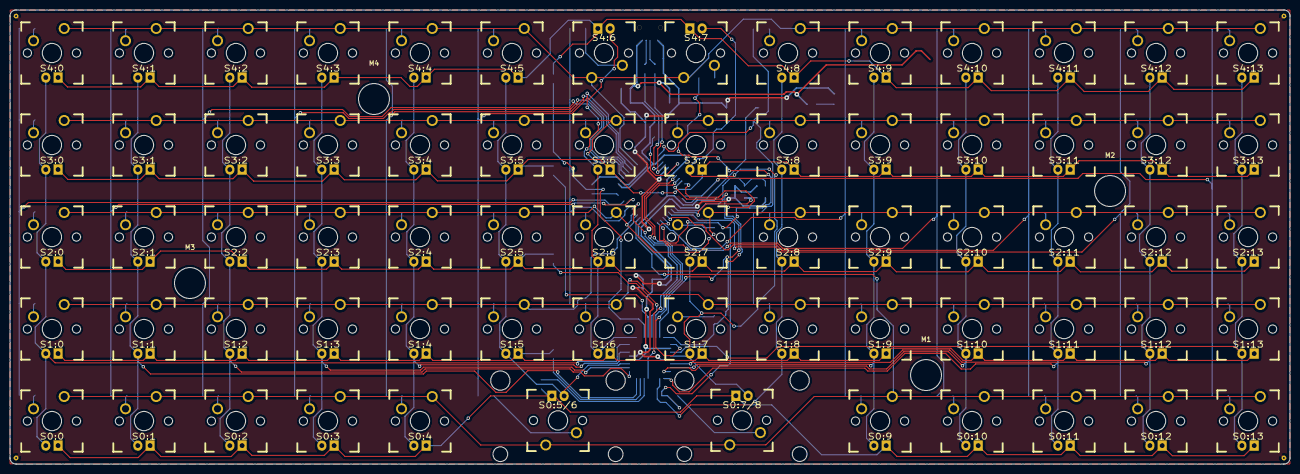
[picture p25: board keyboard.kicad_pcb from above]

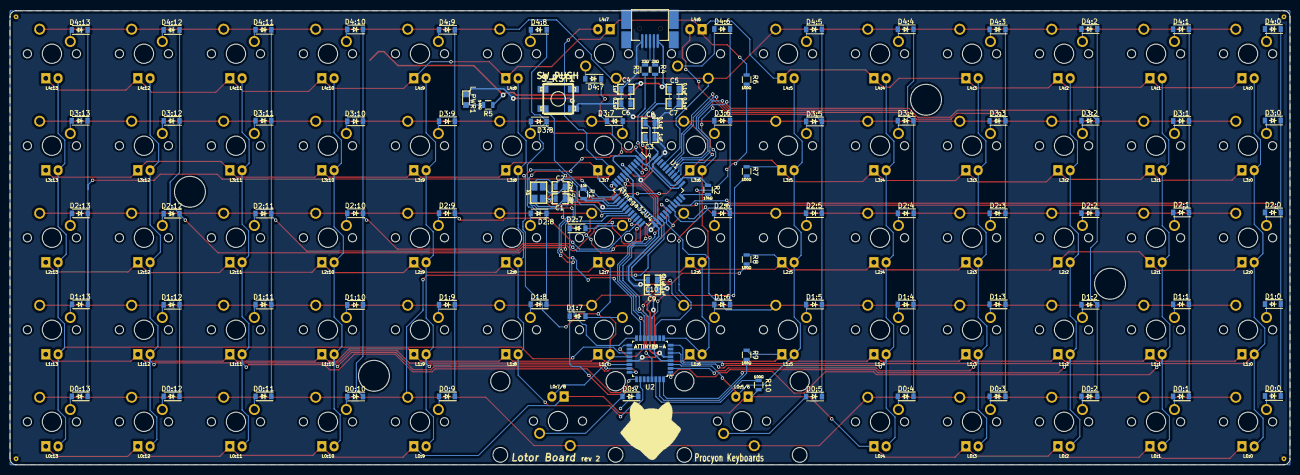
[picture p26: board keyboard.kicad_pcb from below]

Board: 2 copper layers, 265.0 x 94.0 mm, 239 parts (96 on the bottom side), 128 nets.

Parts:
C1, C2: 22pF; 0805C
C3, C4: 1uF; 0805C
C5, C6, C7, C8, C9, C10: 0.1uF; 0805C
D0:0, D0:1, D0:2, D0:3, D0:4, D0:5, D0:7, D0:9, D0:10, D0:11, D0:12, D0:13, D1:0, D1:1, D1:2, D1:3, D1:4, D1:5, D1:6, D1:7, D1:8, D1:9, D1:10, D1:11, D1:12, D1:13, D2:0, D2:1, D2:2, D2:3, D2:4, D2:5, D2:6, D2:7, D2:8, D2:9, D2:10, D2:11, D2:12, D2:13, D3:0, D3:1, D3:2, D3:3, D3:4, D3:5, D3:6, D3:7, D3:8, D3:9, D3:10, D3:11, D3:12, D3:13, D4:0, D4:1, D4:2, D4:3, D4:4, D4:5, D4:6, D4:7, D4:8, D4:9, D4:10, D4:11, D4:12, D4:13: D; SOD-123D
G2: LOGO; racc1
J1: USBMINI_B05; USB_MINI-B-67503
L0:0, L0:1, L0:2, L0:3, L0:4, L0:5/6, L0:7/8, L0:9, L0:10, L0:11, L0:12, L0:13, L1:0, L1:1, L1:2, L1:3, L1:4, L1:5, L1:6, L1:7, L1:8, L1:9, L1:10, L1:11, L1:12, L1:13, L2:0, L2:1, L2:2, L2:3, L2:4, L2:5, L2:6, L2:7, L2:8, L2:9, L2:10, L2:11, L2:12, L2:13, L3:0, L3:1, L3:2, L3:3, L3:4, L3:5, L3:6, L3:7, L3:8, L3:9, L3:10, L3:11, L3:12, L3:13, L4:0, L4:1, L4:2, L4:3, L4:4, L4:5, L4:6, L4:7, L4:8, L4:9, L4:10, L4:11, L4:12, L4:13: LED; CHERRY_MX_LED
L_PWR1: LED; 0805L
M1, M2, M3, M4: MountingHole_6.4mm; MountingHole_6.4mm_M6
R1: 10k; 0805R
R2: 10kΩ; 0805R
R3, R4: 22Ω; 0805R
R5: 140Ω; 0805R
R6, R7, R8, R9, R10: 100Ω; 0805R
S0:0, S0:1, S0:2, S0:3, S0:4, S0:9, S0:10, S0:11, S0:12, S0:13, S1:0, S1:1, S1:2, S1:3, S1:4, S1:5, S1:6, S1:7, S1:8, S1:9, S1:10, S1:11, S1:12, S1:13, S2:0, S2:1, S2:2, S2:3, S2:4, S2:5, S2:6, S2:7, S2:8, S2:9, S2:10, S2:11, S2:12, S2:13, S3:0, S3:1, S3:2, S3:3, S3:4, S3:5, S3:6, S3:7, S3:8, S3:9, S3:10, S3:11, S3:12, S3:13, S4:0, S4:1, S4:2, S4:3, S4:4, S4:5, S4:6, S4:7, S4:8, S4:9, S4:10, S4:11, S4:12, S4:13: SW_PUSH; CHERRY_PCB_100H
S0:5/6, S0:7/8: SW_PUSH; CHERRY_PCB_200H
S_RST1: SW_PUSH; DTSJW-66N
T1, T2, T3, T4: CONN_1; pad
U1: ATmega32U4; ATmega32u4
U2: ATTINY88-A; ATtiny88
X1: CRYSTAL(4pin); Crystal-4pad

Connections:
/led/lcol0: L0:0.2, L1:0.2, L2:0.2, L3:0.2, L4:0.2, U2.8
/led/lcol1: L0:1.2, L1:1.2, L2:1.2, L3:1.2, L4:1.2, U2.32
/led/lcol2: L0:2.2, L1:2.2, L2:2.2, L3:2.2, L4:2.2, U2.1
/led/lcol3: L0:3.2, L1:3.2, L2:3.2, L3:3.2, L4:3.2, U2.2
/led/lcol4: L0:4.2, L1:4.2, L2:4.2, L3:4.2, L4:4.2, U2.6
/led/lcol5: L0:5/6.2, L1:5.2, L2:5.2, L3:5.2, L4:5.2, U2.3
/led/lcol6: L1:6.2, L2:6.2, L3:6.2, L4:6.2, U2.9
/led/lcol7: L0:7/8.2, L1:7.2, L2:7.2, L3:7.2, L4:7.2, U2.20
/led/lcol8: L1:8.2, L2:8.2, L3:8.2, L4:8.2, U2.26
/led/lcol9: L0:9.2, L1:9.2, L2:9.2, L3:9.2, L4:9.2, U2.23
/led/lcol10: L0:10.2, L1:10.2, L2:10.2, L3:10.2, L4:10.2, U2.24
/led/lcol11: L0:11.2, L1:11.2, L2:11.2, L3:11.2, L4:11.2, U2.25
/led/lcol12: L0:12.2, L1:12.2, L2:12.2, L3:12.2, L4:12.2, U2.22
/led/lcol13: L0:13.2, L1:13.2, L2:13.2, L3:13.2, L4:13.2, U2.19
/led/lrow0: R10.2, U2.30
/led/lrow1: R9.2, U2.31
/led/lrow2: R8.2, U2.13
/led/lrow3: R7.2, U2.12
/led/lrow4: R6.2, U2.11
/led/miso: U1.11, U2.16
/led/mosi: U1.10, U2.15
/led/sck: U1.9, U2.17
/led/~reset~: U1.28, U2.29
/led/~ss~: U1.8, U2.14
/matrix/col0: D0:0.1, D1:0.1, D2:0.1, D3:0.1, D4:0.1, U1.31
/matrix/col1: D0:1.1, D1:1.1, D2:1.1, D3:1.1, D4:1.1, U1.30
/matrix/col2: D0:2.1, D1:2.1, D2:2.1, D3:2.1, D4:2.1, U1.37
/matrix/col3: D0:3.1, D1:3.1, D2:3.1, D3:3.1, D4:3.1, U1.38
/matrix/col4: D0:4.1, D1:4.1, D2:4.1, D3:4.1, D4:4.1, U1.39
/matrix/col5: D0:5.1, D1:5.1, D2:5.1, D3:5.1, D4:5.1, U1.40
/matrix/col6: D1:6.1, D2:6.1, D3:6.1, D4:6.1, U1.29
/matrix/col7: D0:7.1, D1:7.1, D2:7.1, D3:7.1, D4:7.1, U1.22
/matrix/col8: D1:8.1, D2:8.1, D3:8.1, D4:8.1, U1.1
/matrix/col9: D0:9.1, D1:9.1, D2:9.1, D3:9.1, D4:9.1, U1.21
/matrix/col10: D0:10.1, D1:10.1, D2:10.1, D3:10.1, D4:10.1, U1.20
/matrix/col11: D0:11.1, D1:11.1, D2:11.1, D3:11.1, D4:11.1, U1.19
/matrix/col12: D0:12.1, D1:12.1, D2:12.1, D3:12.1, D4:12.1, U1.18
/matrix/col13: D0:13.1, D1:13.1, D2:13.1, D3:13.1, D4:13.1, U1.12
/matrix/row0: S0:0.1, S0:1.1, S0:2.1, S0:3.1, S0:4.1, S0:5/6.1, S0:7/8.1, S0:9.1, S0:10.1, S0:11.1, S0:12.1, S0:13.1, U1.25
/matrix/row1: S1:0.1, S1:1.1, S1:2.1, S1:3.1, S1:4.1, S1:5.1, S1:6.1, S1:7.1, S1:8.1, S1:9.1, S1:10.1, S1:11.1, S1:12.1, S1:13.1, U1.26
/matrix/row2: S2:0.1, S2:1.1, S2:2.1, S2:3.1, S2:4.1, S2:5.1, S2:6.1, S2:7.1, S2:8.1, S2:9.1, S2:10.1, S2:11.1, S2:12.1, S2:13.1, U1.27
/matrix/row3: S3:0.1, S3:1.1, S3:2.1, S3:3.1, S3:4.1, S3:5.1, S3:6.1, S3:7.1, S3:8.1, S3:9.1, S3:10.1, S3:11.1, S3:12.1, S3:13.1, U1.36
/matrix/row4: S4:0.1, S4:1.1, S4:2.1, S4:3.1, S4:4.1, S4:5.1, S4:6.1, S4:7.1, S4:8.1, S4:9.1, S4:10.1, S4:11.1, S4:12.1, S4:13.1, U1.41
/~RES~: R1.2, S_RST1.2, U1.13
GND: C1.2, C2.2, C3.2, C4.2, C5.2, C6.2, C7.2, C8.2, C9.2, C10.2, J1.5, L_PWR1.1, R2.1, S_RST1.1, T1.1, T2.1, T3.1, T4.1, U1.5, U1.15, U1.23, U1.35, U1.43, U2.5, U2.21, X1.2, X1.4
unnamed: C1.1, U1.17, X1.1
unnamed: C2.1, U1.16, X1.3
unnamed: C3.1, U1.6
unnamed: D0:0.2, S0:0.2
unnamed: D0:1.2, S0:1.2
unnamed: D0:2.2, S0:2.2
unnamed: D0:3.2, S0:3.2
unnamed: D0:4.2, S0:4.2
unnamed: D0:5.2, S0:5/6.2
unnamed: D0:7.2, S0:7/8.2
unnamed: D0:9.2, S0:9.2
unnamed: D0:10.2, S0:10.2
unnamed: D0:11.2, S0:11.2
unnamed: D0:12.2, S0:12.2
unnamed: D0:13.2, S0:13.2
unnamed: D1:0.2, S1:0.2
unnamed: D1:1.2, S1:1.2
unnamed: D1:2.2, S1:2.2
unnamed: D1:3.2, S1:3.2
unnamed: D1:4.2, S1:4.2
unnamed: D1:5.2, S1:5.2
unnamed: D1:6.2, S1:6.2
unnamed: D1:7.2, S1:7.2
unnamed: D1:8.2, S1:8.2
unnamed: D1:9.2, S1:9.2
unnamed: D1:10.2, S1:10.2
unnamed: D1:11.2, S1:11.2
unnamed: D1:12.2, S1:12.2
unnamed: D1:13.2, S1:13.2
unnamed: D2:0.2, S2:0.2
unnamed: D2:1.2, S2:1.2
unnamed: D2:2.2, S2:2.2
unnamed: D2:3.2, S2:3.2
unnamed: D2:4.2, S2:4.2
unnamed: D2:5.2, S2:5.2
unnamed: D2:6.2, S2:6.2
unnamed: D2:7.2, S2:7.2
unnamed: D2:8.2, S2:8.2
unnamed: D2:9.2, S2:9.2
unnamed: D2:10.2, S2:10.2
unnamed: D2:11.2, S2:11.2
unnamed: D2:12.2, S2:12.2
unnamed: D2:13.2, S2:13.2
unnamed: D3:0.2, S3:0.2
unnamed: D3:1.2, S3:1.2
unnamed: D3:2.2, S3:2.2
unnamed: D3:3.2, S3:3.2
unnamed: D3:4.2, S3:4.2
unnamed: D3:5.2, S3:5.2
unnamed: D3:6.2, S3:6.2
unnamed: D3:7.2, S3:7.2
unnamed: D3:8.2, S3:8.2
unnamed: D3:9.2, S3:9.2
unnamed: D3:10.2, S3:10.2
unnamed: D3:11.2, S3:11.2
unnamed: D3:12.2, S3:12.2
unnamed: D3:13.2, S3:13.2
unnamed: D4:0.2, S4:0.2
unnamed: D4:1.2, S4:1.2
unnamed: D4:2.2, S4:2.2
unnamed: D4:3.2, S4:3.2
unnamed: D4:4.2, S4:4.2
unnamed: D4:5.2, S4:5.2
unnamed: D4:6.2, S4:6.2
unnamed: D4:7.2, S4:7.2
unnamed: D4:8.2, S4:8.2
unnamed: D4:9.2, S4:9.2
unnamed: D4:10.2, S4:10.2
unnamed: D4:11.2, S4:11.2
unnamed: D4:12.2, S4:12.2
unnamed: D4:13.2, S4:13.2
unnamed: J1.2, R4.2
unnamed: J1.3, R3.2
unnamed: L0:0.1, L0:1.1, L0:2.1, L0:3.1, L0:4.1, L0:5/6.1, L0:7/8.1, L0:9.1, L0:10.1, L0:11.1, L0:12.1, L0:13.1, R10.1
unnamed: L1:0.1, L1:1.1, L1:2.1, L1:3.1, L1:4.1, L1:5.1, L1:6.1, L1:7.1, L1:8.1, L1:9.1, L1:10.1, L1:11.1, L1:12.1, L1:13.1, R9.1
unnamed: L2:0.1, L2:1.1, L2:2.1, L2:3.1, L2:4.1, L2:5.1, L2:6.1, L2:7.1, L2:8.1, L2:9.1, L2:10.1, L2:11.1, L2:12.1, L2:13.1, R8.1
unnamed: L3:0.1, L3:1.1, L3:2.1, L3:3.1, L3:4.1, L3:5.1, L3:6.1, L3:7.1, L3:8.1, L3:9.1, L3:10.1, L3:11.1, L3:12.1, L3:13.1, R7.1
unnamed: L4:0.1, L4:1.1, L4:2.1, L4:3.1, L4:4.1, L4:5.1, L4:6.1, L4:7.1, L4:8.1, L4:9.1, L4:10.1, L4:11.1, L4:12.1, L4:13.1, R6.1
unnamed: L_PWR1.2, R5.2
unnamed: R2.2, U1.33
unnamed: R3.1, U1.4
unnamed: R4.1, U1.3
VCC: C4.1, C5.1, C6.1, C7.1, C8.1, C9.1, C10.1, J1.1, R1.1, R5.1, U1.2, U1.7, U1.14, U1.24, U1.34, U1.44, U2.4, U2.18

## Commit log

2016-02-29 adding images, kicad, and autocad files
    [case.dwg, keyboard-B.Cu.dxf, keyboard-B.SilkS.dxf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]
2016-04-18 pushing everything cuz i'm lazy, will cull later
    [case.dwg, keyboard.dsn, keyboard.kicad_pcb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]
2016-04-18 culling old materiasl and backup files
    [keyboard-B.Cu.dxf, keyboard-B.SilkS.dxf, keyboard-Edge.Cuts.dxf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]
2016-04-18 adding gerber files
    [keyboard-B.Adhes.gbr, keyboard-B.CrtYd.gbr, keyboard-B.Cu.gbr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]
2016-04-18 updated to fix some errors
    [keyboard-B.Adhes.gbr, keyboard-B.CrtYd.gbr, keyboard-B.Cu.gbr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]
2016-04-19 separated grid and MIT layouts
    [case.dwg, keyboard.kicad_pcb, keyboard.sch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]
2016-04-19 adding mit and grid layouts
    [keyboard-MIT-B.Adhes.dxf, keyboard-MIT-B.CrtYd.dxf, keyboard-MIT-B.Cu.dxf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]
2016-04-21 separating the different layouts
    [case.dwg, case.stl, keyboard-MIT.kicad_pcb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]
2016-05-17 changing structure
    [case.dwg, keyboard-B.Cu.dxf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]
2016-05-17 updating case and adding cover
    [case.dwg, case.stl, cover.dwg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]
2016-05-17 adding gerber files for lotor rev 1
    [keyboard-B.Cu.gbr, keyboard-B.Mask.gbr, keyboard-B.SilkS.gbr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]
2016-05-31 new plate
    [plate-MIT.dxf, plate-grid.dxf]
2016-09-12 big update, got quote :(
    [case.dwg, case.stl, casebackview.dxf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]
2017-03-02 adding slices for acrylic 'sandwich' cases to be produced
    [bottom-middle.dwg, bottom-middle.stl, bottom.dwg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]
2017-03-04 slices update
    [slices.dwg, slices.stl]
2017-03-04 new slices
    [bottom-middle.stl, bottom.stl, top-middle.stl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]
2017-04-02 making revisions
    [keyboard-MIT.kicad_pcb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]
2017-04-03 adding prototype for revision 3: with more support for other layouts
    [keyboard-rev3.kicad_pcb, keyboard-rev3.sch, led-rev3.sch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]
2017-04-03 updating rev2
    [led.sch, matrix.sch]
2017-04-03 more updates for rev2
    [keyboard-B.Cu.gbr, keyboard-B.Mask.gbr, keyboard-B.SilkS.gbr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]
2017-06-19 submitting quote for case and cover
    [case.dwg, caseback.dxf, caseright.dxf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]
2017-06-19 create and submitted .igs files for case and cover
    [case.igs, cover.igs]
